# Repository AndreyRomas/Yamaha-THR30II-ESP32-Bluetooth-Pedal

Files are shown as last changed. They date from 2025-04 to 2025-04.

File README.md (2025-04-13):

Minimalist wireless pedal based on esp32-s3 for Yamaha THR30II that switches between two presets.

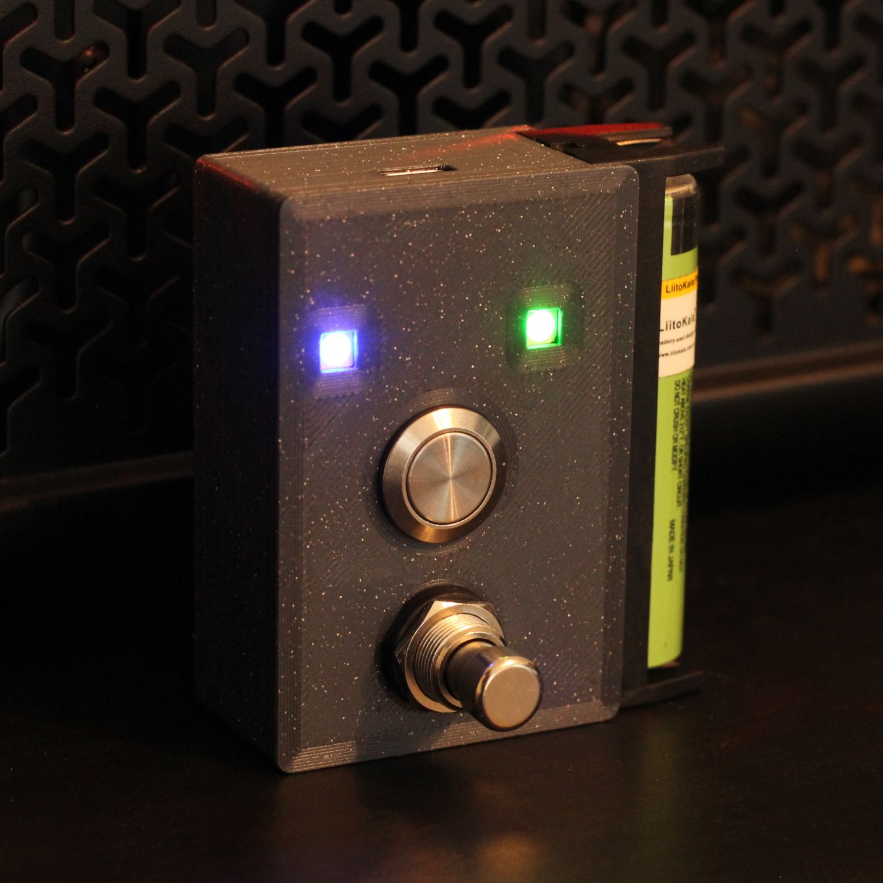
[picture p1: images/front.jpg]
device


Warning: although it is highly unlikely to break anything, I cannot guarantee that this cannot damage your amp. Do it at your own risk. 

I was not able to find any other projects like that, so I decided to develop my own and push it to github.
There are multiple projects for devices that control the amp via USB cable. Or Bluetooth, but instead of doing it directly, it connects an esp-based device to a phone running the official application that is connected to the amp.

This one connects to the amp directly. It does it pretty quickly btw. It can't be used at the same time when your phone is connected to the amp. If the signal is lost, it reconnects. 

There are 2 LEDs: the left one represents connection. If it is yellow, it tries to connect to the amp. As soon as the connection is established it turns blue. The right one represents the battery charge level. Red, yellow or green depending on the current battery's voltage. There 2 buttons: the top one wakes the device from deep sleep, and the same one sends it into deep sleep mode. The bottom one switches between presets.

I'm not a huge expert in bluetooth or development for microcontrollers. But after endless experiments, I finally have the working code. 
It is developed and tested with the latest firmware currently available v1.5.0. It might work with the newer ones, but I'll do my best to update the code if something changes after an update.

The app exchanges many more packets with the amp, but I found that most of them can be excluded except for those you see in the code.

I do not expect people to reproduce the project 1:1, because I believe it is pretty easy to design it better and just use the code as a base. But just in case I attach the 3d model, schematics, and hardware list I used to build the final device. (Please first of all check that the code works with your amp.) Feel free to use it fully or partially:

- Seeed Xiao ESP32-S3
- BHC-18650-1P battery holder
- Metal button ø16mm (random one I found at a local shop)
- Same for the footswitch, but something very similar I find by googling "PBS-24-202"
- 2 ws2812b leds
- 4 x 3mm thread inserts. Outer diameter 4.2mm

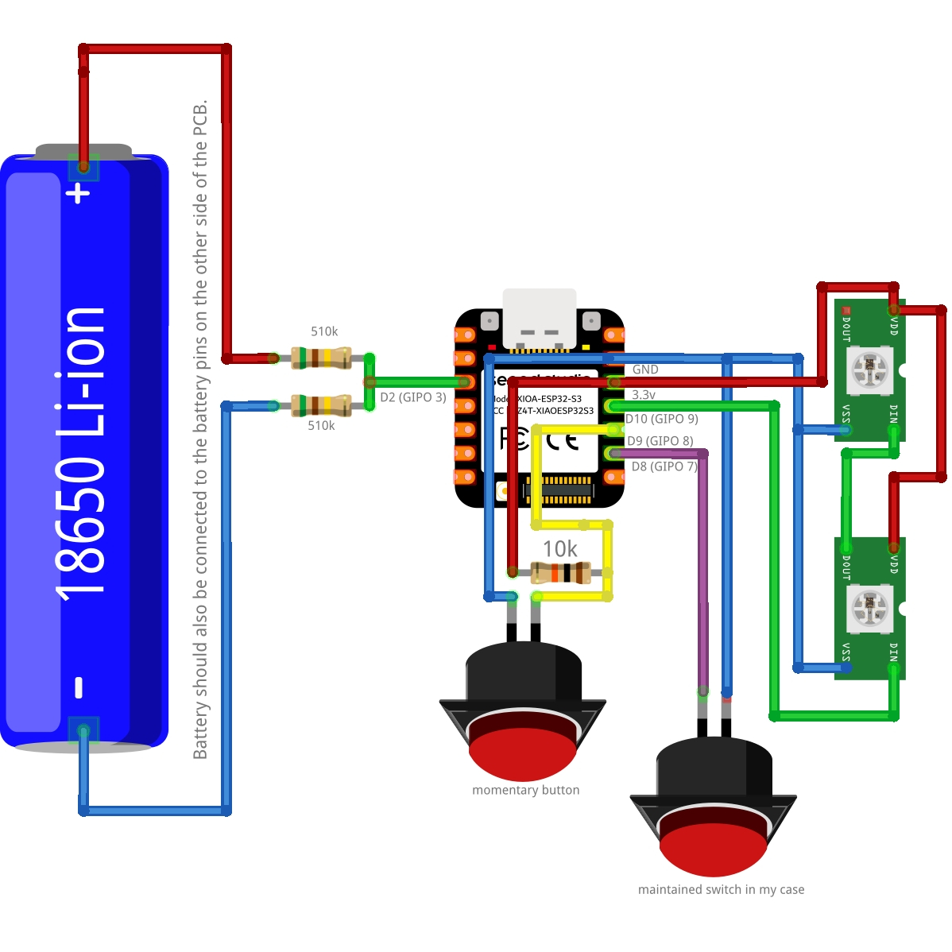
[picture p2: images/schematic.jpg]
schematics


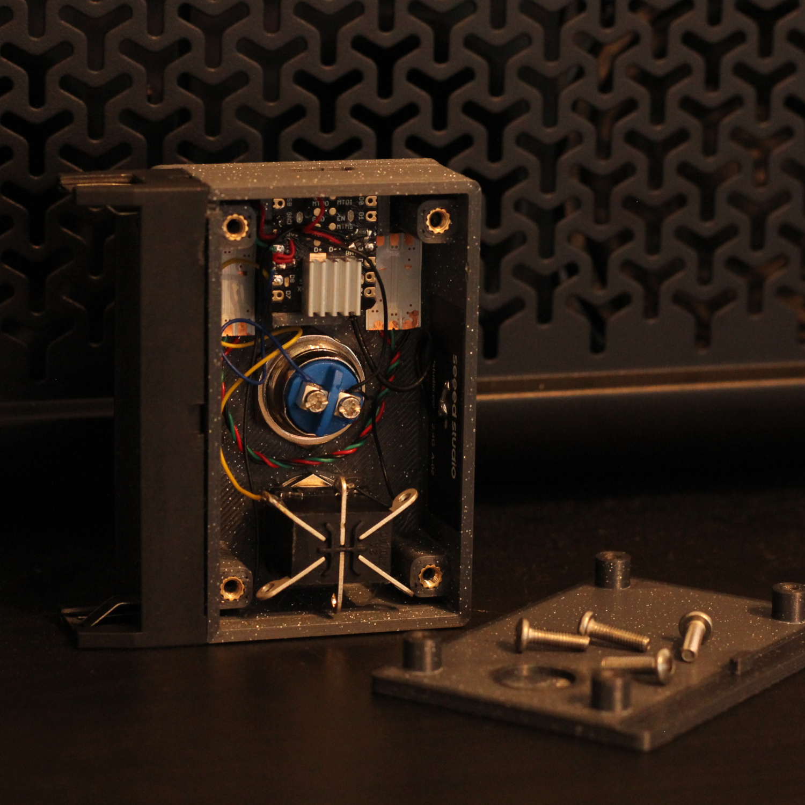
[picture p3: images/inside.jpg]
inside


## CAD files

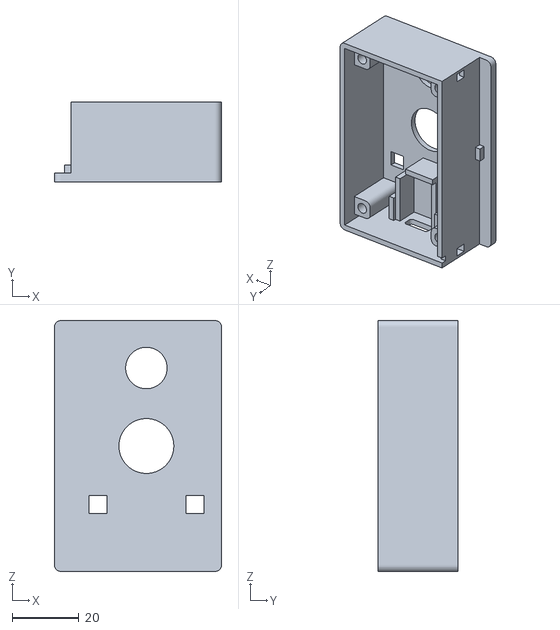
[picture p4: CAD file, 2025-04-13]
3d/pedal_top.stl
50.0 x 24.0 x 75.0

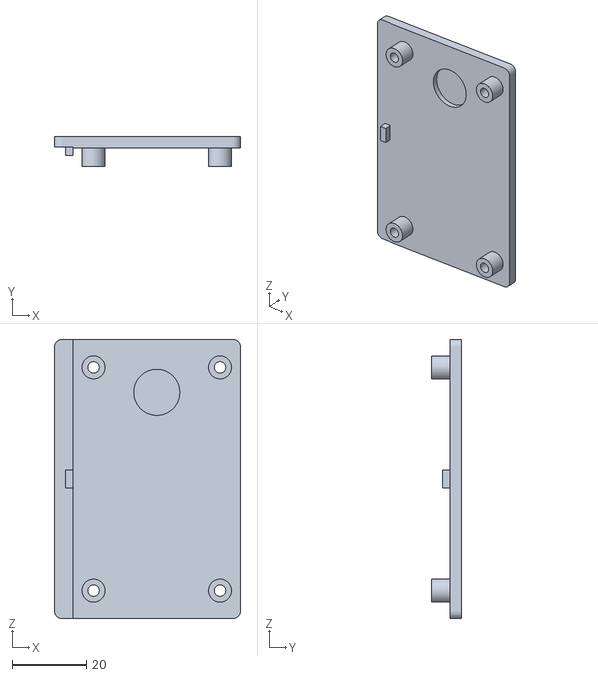
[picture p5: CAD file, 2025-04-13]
3d/pedal_bottom.stl
50.0 x 8.00 x 75.0

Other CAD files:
3d/pedal.f3d

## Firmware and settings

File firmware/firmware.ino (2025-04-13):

#include <FastLED.h>
#include "BLEDevice.h"

// PINS
#define SWITCH_PIN 7
#define POWER_BUTTON_PIN GPIO_NUM_8
#define WS2812_DATA_PIN 9
#define BATTERY_VOLTAGE_PIN  3

// Config
#define NUM_LEDS 2
#define VOLTAGE_DIVIDER_RATIO 0.5 // Battery is connected to an analog pin to measure its voltage.
#define BLE_DEVICE_NAME "LE_THRII"
#define DEBUG false

// Voltage thresholds
#define VOLTAGE_THRESHOLD_LOW 3.3
#define VOLTAGE_THRESHOLD_MEDIUM 3.7

CRGB leds[NUM_LEDS];

BLEScan* pBLEScan;
BLEClient* pClient;
BLERemoteCharacteristic* pRemoteCharacteristic;

static BLEUUID serviceUUID("03b80e5a-ede8-4b33-a751-6ce34ec4c700");
static BLEUUID charUUID("7772e5db-3868-4112-a1a9-f2669d106bf3");

byte currentPreset = 1;
bool currentSwitchState = LOW;

byte activateMessage1[]    = { 0x80, 0x80, 0xF0, 0x00, 0x01, 0x0C, 0x24, 0x02, 0x4D, 0x00, 0x01, 0x00, 0x00, 0x07, 0x00, 0x04, 0x00, 0x00, 0x00, 0x04, 0x00, 0x00, 0x00, 0x00, 0x00, 0x00, 0x00, 0x00, 0x00, 0x00, 0x80, 0xF7 };
byte activateMessage2[]    = { 0x80, 0x80, 0xF0, 0x00, 0x01, 0x0C, 0x24, 0x02, 0x4D, 0x00, 0x02, 0x00, 0x00, 0x03, 0x28, 0x72, 0x4D, 0x54, 0x5D, 0x00, 0x00, 0x00, 0x80, 0xF7 };
byte changePresetMessage[] = { 0x80, 0x80, 0xF0, 0x00, 0x01, 0x0C, 0x24, 0x02, 0x4D, 0x01, 0x00, 0x00, 0x00, 0x0B, 0x00, 0x0E, 0x00, 0x00, 0x00, 0x04, 0x00, 0x00, 0x00, 0x00, 0x00, 0x00, 0x00, 0x00, 0x00, 0x00, 0x80, 0xF7 };

void setup() {
  if (DEBUG) Serial.begin(57600);
  if (DEBUG) Serial.println("Start");

  pinMode(SWITCH_PIN, INPUT_PULLUP);
  pinMode(POWER_BUTTON_PIN, INPUT);

  if (digitalRead(POWER_BUTTON_PIN) == LOW) {
    // Waiting for the power button to be released so it would not go into sleep mode again.
    waitForButtonRelease(POWER_BUTTON_PIN);
  } else {
    // Device was powered on due to battery insertion or USB connection, without a button press. It should not power up.
    powerOff();
  }

  FastLED.addLeds<NEOPIXEL, WS2812_DATA_PIN>(leds, NUM_LEDS);
  FastLED.setBrightness(50);

  xTaskCreatePinnedToCore(backgroundTask, "backgroundTask", 10000, NULL, 1, NULL,  1);

  currentSwitchState = digitalRead(SWITCH_PIN);

  BLEDevice::init("ESP32_Client");

  initConnect();
}

void powerOff() {
  FastLED.clear();
  FastLED.show();

  // Waiting for the power button to be released so it would not wake up right after going into sleep mode.
  waitForButtonRelease(POWER_BUTTON_PIN);

  esp_sleep_enable_ext0_wakeup(POWER_BUTTON_PIN, 0);
  esp_deep_sleep_start();
}

void initConnect() {
  setStatusLED(CRGB::Orange);
  if (DEBUG) Serial.println("Init connect");

  while (!connectToTHR());

  if (pRemoteCharacteristic->canNotify()) {
    pRemoteCharacteristic->registerForNotify(notifyCallback);
  }

  if (DEBUG) Serial.println("Register for notify");

  pRemoteCharacteristic->writeValue((uint8_t*)activateMessage1, sizeof(activateMessage1), false);
  pRemoteCharacteristic->writeValue((uint8_t*)activateMessage2, sizeof(activateMessage2), false);

  if (DEBUG) Serial.println("Sent activate request");

  setStatusLED(CRGB::Blue);
}


void loop() {
  if (pRemoteCharacteristic && pClient->isConnected()) {
    if (currentSwitchState != digitalRead(SWITCH_PIN)) {
      currentPreset = 3 - currentPreset;
      sendChangePresetMessage(currentPreset);
      delay(100); // debouncing
      currentSwitchState = digitalRead(SWITCH_PIN);
    }
  } else {
    initConnect();
  }
}

bool connectToTHR() {
  pBLEScan = BLEDevice::getScan();
  pBLEScan->setActiveScan(true);
  BLEScanResults* foundDevices = pBLEScan->start(5, false);

  for (int i = 0; i < foundDevices->getCount(); i++) {
    BLEAdvertisedDevice device = foundDevices->getDevice(i);
    if (device.getName() == BLE_DEVICE_NAME) {
      BLEDevice::setEncryptionLevel(ESP_BLE_SEC_ENCRYPT);

      pClient = BLEDevice::createClient();

      if (!pClient->connect(&device)) {
        if (DEBUG) Serial.println("Connect failed");
        return false;
      }

      BLERemoteService* pRemoteService = pClient->getService(serviceUUID);

      if (!pRemoteService) {
        if (DEBUG) Serial.println("Get service failed");
        return false;
      }

      pRemoteCharacteristic = pRemoteService->getCharacteristic(charUUID);

      if (!pRemoteCharacteristic) {
        if (DEBUG) Serial.println("Get characteristic failed");
        return false;
      }

      pClient->setMTU(40);

      if (DEBUG) Serial.println("Connected");
      return true;
    }
  }

  if (DEBUG) Serial.println("Device not found");
  return false;
}

void backgroundTask(void *pvParameters) {
  unsigned long previousMillis = 0;
  const long interval = 1000;

  for (;;) {
    unsigned long currentMillis = millis();

    if (currentMillis - previousMillis >= interval) {
      previousMillis = currentMillis;
      float voltage = analogReadMilliVolts(BATTERY_VOLTAGE_PIN) / VOLTAGE_DIVIDER_RATIO / 1000.0;

      if (voltage < VOLTAGE_THRESHOLD_LOW) {
        setBatteryLED(CRGB::Red);
      } else if (voltage >= VOLTAGE_THRESHOLD_LOW && voltage <= VOLTAGE_THRESHOLD_MEDIUM) {
        setBatteryLED(CRGB::Orange);
      } else {
        setBatteryLED(CRGB::Green);
      }

      FastLED.show();
    }

    if (digitalRead(POWER_BUTTON_PIN) == LOW) {
      powerOff();
    }
  }
}

void sendChangePresetMessage(byte presetNumber) {
  changePresetMessage[24] = presetNumber - 1;
  pRemoteCharacteristic->writeValue((uint8_t*)changePresetMessage, sizeof(changePresetMessage), false);
}

static void notifyCallback(BLERemoteCharacteristic* pBLERemoteCharacteristic, uint8_t* pData, size_t length, bool isNotify) {
  if (DEBUG) {
    for (size_t i = 0; i < length; i++) {
      Serial.print(pData[i], HEX);
      Serial.print(" ");
      if (pData[i] == 0xF7) Serial.println();
    }
  }
}

void waitForButtonRelease(int buttonPin) {
  while (digitalRead(buttonPin) == LOW);
  delay(100);
}

void setStatusLED(CRGB color) {
  leds[1] = color;
  FastLED.show();
}

void setBatteryLED(CRGB color) {
  leds[0] = color;
  FastLED.show();
}
